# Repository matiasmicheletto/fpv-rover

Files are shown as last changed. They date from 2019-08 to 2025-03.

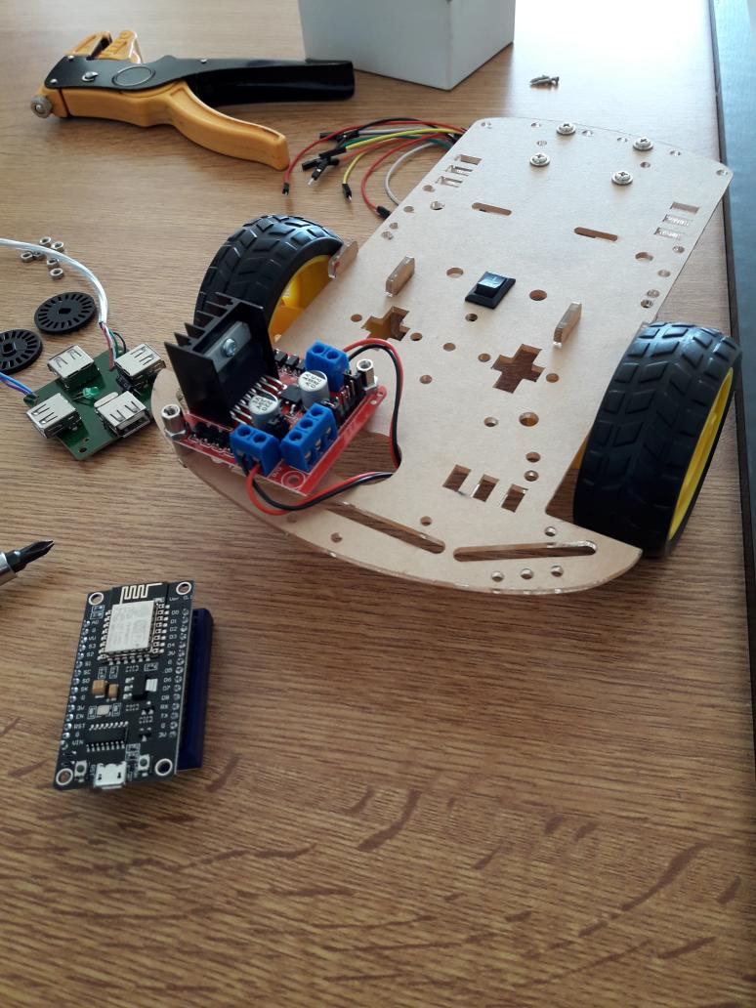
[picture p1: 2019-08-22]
img/v1-assembling/Assembling_2.jpg

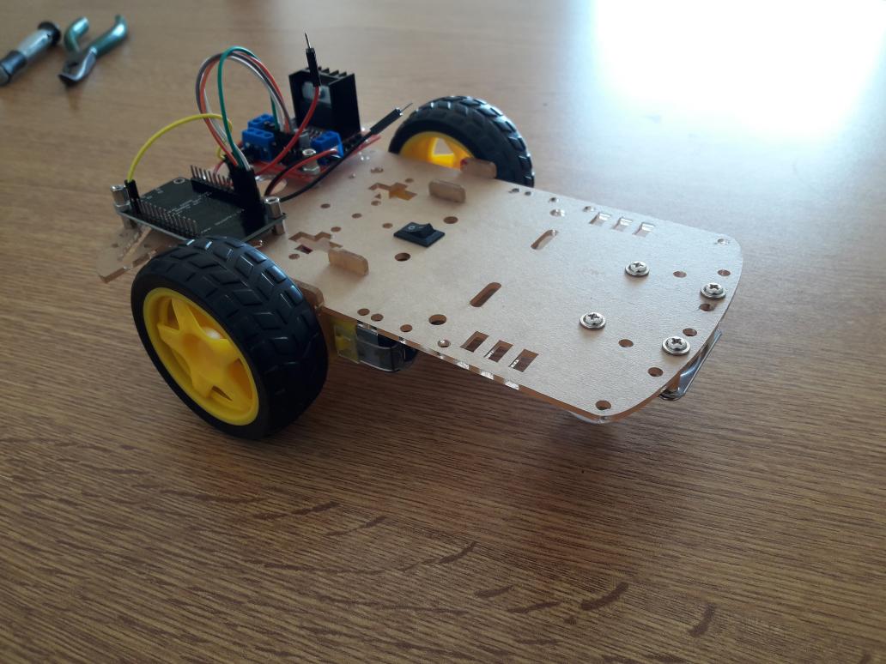
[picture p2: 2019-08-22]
img/v1-assembling/Assembling_3.jpg

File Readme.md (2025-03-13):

# FPV Wi-Fi rover 

A three-wheeled rover built using a prototyping [chassis kit](https://www.amazon.com/perseids-Chassis-Encoder-Wheels-Battery/dp/B07DNYQ3PX) and the [ESP32-CAM](https://www.amazon.com/ESP32-CAM-MB-Aideepen-ESP32-CAM-Bluetooth-Arduino/dp/B0948ZFTQZ/ref=sr_1_2_sspa) board.  

By means of a HUD Display running in your browser, you can see the rover's point of view, and by moving the cursor over the screen, you can control the rover through WebSocket commands.  

## Demo
Demo (https://www.youtube.com/watch?v=7270GWGmxQA)  

## Requirements

  - ESP32-CAM.  
  - L298n Dual Full-Bridge.  
  - Kit 3 wheeled robot: chassis, motors, wheels and battery sockets.  
  - WiFi network (no internet needed).  
  - Web browser with WebSocket API support.  

## Getting started

  1. Build the rover attaching motors to the chasis, L298n bridge, power supply and on-off switch. Use at least 9V as supply, and not higher than 12V. A set of seven 1.5V AA batteries will make the job.     
  2. Create a ``credentials.h`` file in the [firmware/src/](firmware/src/) folder with your local WiFi SSID and password, for example:
  ```cpp
    const char* ssid = "MY_SSID";  
    const char* password = "my_pass";  
  ```
  3. Compile and upload the firmware to the ESP32-CAM board using the corresponding programmer shield. You can use the Arduino IDE or any other platform of your choice.  
  4. Use a serial monitor to see the IP address that your local network provided to the rover's ESP32-CAM board. After that, you can disconnect the board from the programmer shield.  
  5. Connect the microcontroller to the bridge using the pin map configured in [firmware/src/config.h](firmware/src/config.h). Use the 5V output of the bridge as power supply for the microcontroller. Now, the harware configuration is done, and the rover should be ready to use.  
  6. In your computer connected to the same WiFi network of the rover, setup a local server to serve the [client](client/index.html) web application. Open the app with your browser, depending on the server application, usually it is hosted with the URL: http://localhost:8080.   
  7. Set the IP address of the rover in the input and hit the "connect" button. You should see the video captured by the rovers camera as the background of the screen. If that doesn't work, then check the [client/js/index.js](client/js/index.js) script to look for any mismatch between ports or IP configurations.  
  8. That's it, control the rover by moving the cursor over the screen and have fun!  

## License

This project is published under the GPL V3.0 license.

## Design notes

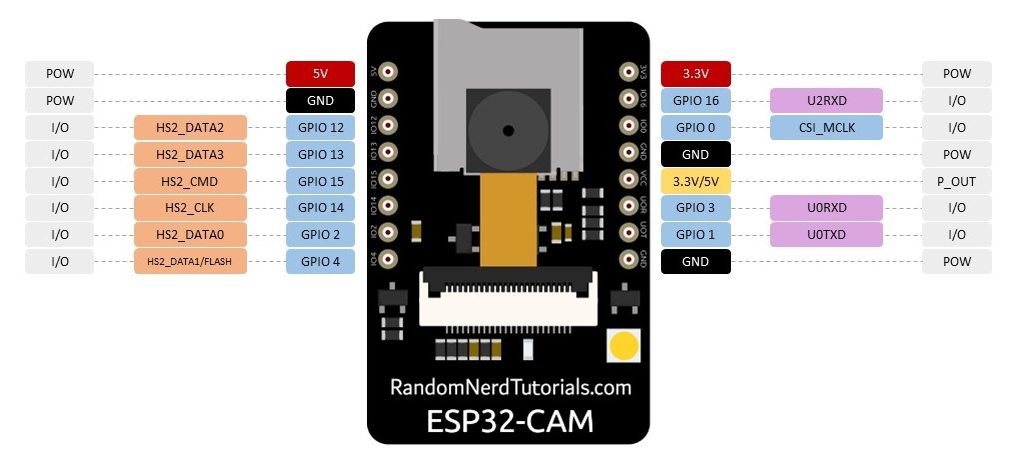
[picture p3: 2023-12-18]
doc/ESP32CAM_pinout.jpg

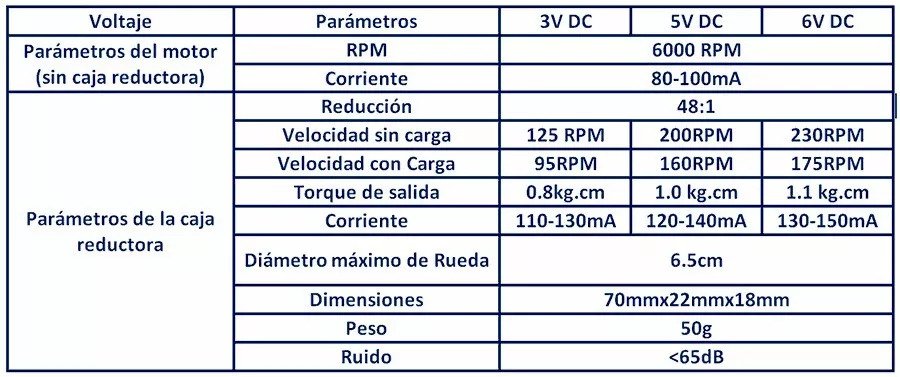
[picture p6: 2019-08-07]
doc/motor.jpg

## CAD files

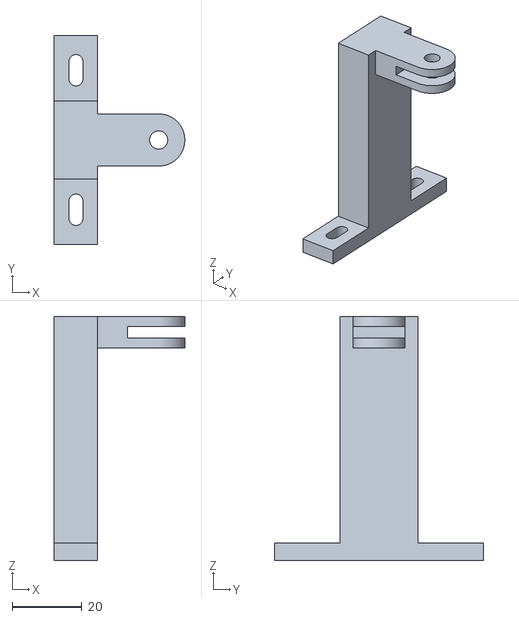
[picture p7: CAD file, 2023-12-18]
3d-models/gopro_mount_chasis.stl
37.5 x 60.0 x 70.0

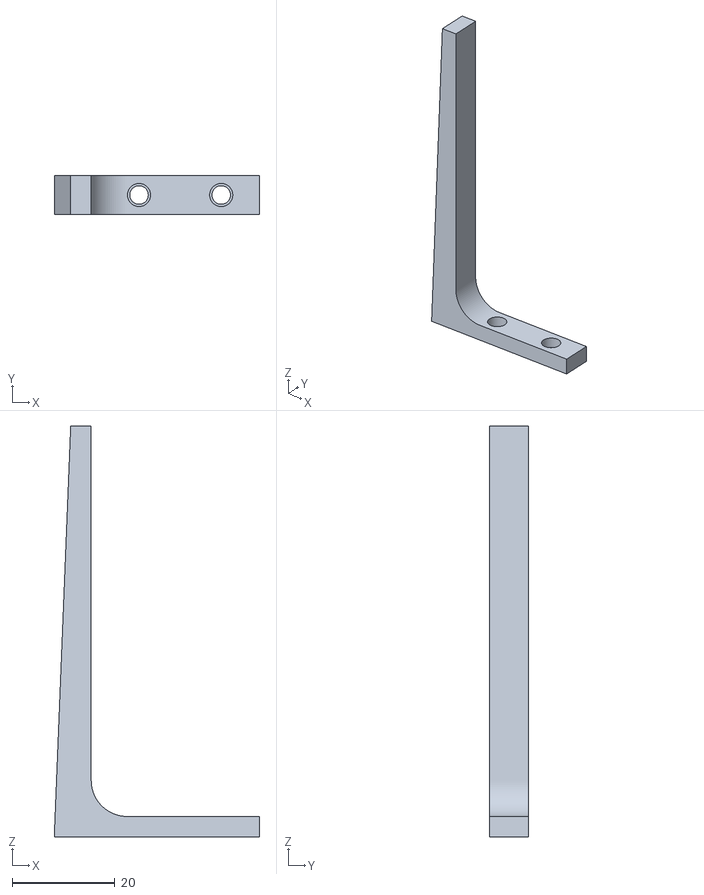
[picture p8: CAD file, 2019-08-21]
3d-models/smartphone_holder.stl
40.0 x 7.50 x 80.0

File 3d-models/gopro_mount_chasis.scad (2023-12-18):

$fn = 100;

// Adapter dimensions
Ro = 7.5;
Ri = 2.6;
L = 35;
Lc = 17;
Hc = 3.2;
Ht = 2.9;

// Holder and base dimensions
Wb = 12.5; // Base width
Lb = 60; // Base length
Hbb = 5; // Base height
Hbt = 65; // Holder height (mounted on base)
rh = 2; // Hole radius
lh = 5; // Hole length (from circles centers)
Sh = 40; // Holes separation



module half(){
    translate([L/2, 0, 0])
        difference(){
            union(){
                cylinder(h = Ht, r = Ro, center = true);
                translate([-L/4, 0, 0])
                    cube([L/2, Ro*2, Ht], center = true);
            }
            cylinder(h = Ht, r = Ri, center = true);
        }
}

module center(){
    translate([Lc/4, 0, Hc/2])
        cube([Lc/2, Ro*2, Hc], center = true);
}


module adapter() {
    translate([0,0,(Hc+Ht)/2]) half();
    translate([0,0,-(Hc+Ht)/2]) half();
    translate([0,0,-Hc/2]) center();
}

module screw_hole() {
    linear_extrude(height = Hbb, center = true, convexity = 10, twist = 0)
    hull() {
        translate([0,lh/2,0]) circle(rh);
        translate([0,-lh/2,0]) circle(rh);
    }
}
    

module base() {
    union() { // Base and holder
        difference() { // Base with holes
            cube([Wb, Lb, Hbb], center = true);
            translate([0, Sh/2, 0]) screw_hole();
            translate([0, -Sh/2, 0]) screw_hole();
        }
        translate([0, 0, (Hbb+Hbt)/2])
            cube([Wb, 3*Ro, Hbt], center = true);
    }
}

module holder() {
    base();
    translate([Wb/2,0,Hbb/2+Hbt-Ht-Hc/2]) adapter();
}

holder();

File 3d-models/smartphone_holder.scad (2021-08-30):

$fn=50;

// Dimensiones
L = 40; // Largo del pie
H = 80; // Altura
W = 7.5; // Ancho
R = 7; // Radio curvatura angulo
// Orificios para tornillos
sep = 16; // Separacion
db = 7.5; // Distancia al borde del pie
// Largo y alto a quitar para el ahuecamiento central
L2 = L*0.82; 
H2 = H-4; 
// Dimensiones rectangulo diagonal
w = L-L2-H+H2; 
s = sqrt(H*H+w*w); 

module rem(){
    union(){ // Recorte interior
        translate([(L-L2+R)/2,0,(H-H2)/2])
            cube([(L2-R),W,H2], center = true);
        
        translate([(L-L2)/2,0,(H-H2+R)/2])
            cube([L2,W,H2-R], center = true);
        
        translate([L/2-L2+R,0,H/2-H2+R])
        rotate([0,90,90])
            cylinder(r = R, h = W+1, center = true);
    }
    
    // Recorte diagonal
    translate([-L/2,-W/2,-H/2])
    rotate([0,-asin(H/s),0])
        cube([s,W,w*H/s]);
}

module holes(){
        
    Rh1 = 2.25; // Radio para cabeza del tornillo
    Rh2 = 1.8; // Radio para rosca del tornillo
    ph = 1.5; // Espesor de la zona de ajuste

    translate([L/2-db,0,-H2/2+ph/2])
        cylinder(r = Rh1, h = H-H2-ph, center = true);
    translate([L/2-db,0,-H2/2])
        cylinder(r = Rh2, h = H-H2, center = true);
    
    translate([L/2-db-sep,0,-H2/2+ph/2])
        cylinder(r = Rh1, h = H-H2-ph, center = true);
    translate([L/2-db-sep,0,-H2/2])
        cylinder(r = Rh2, h = H-H2, center = true);
}


difference(){
    cube([L,W,H], center = true);
    rem();
    holes();
}

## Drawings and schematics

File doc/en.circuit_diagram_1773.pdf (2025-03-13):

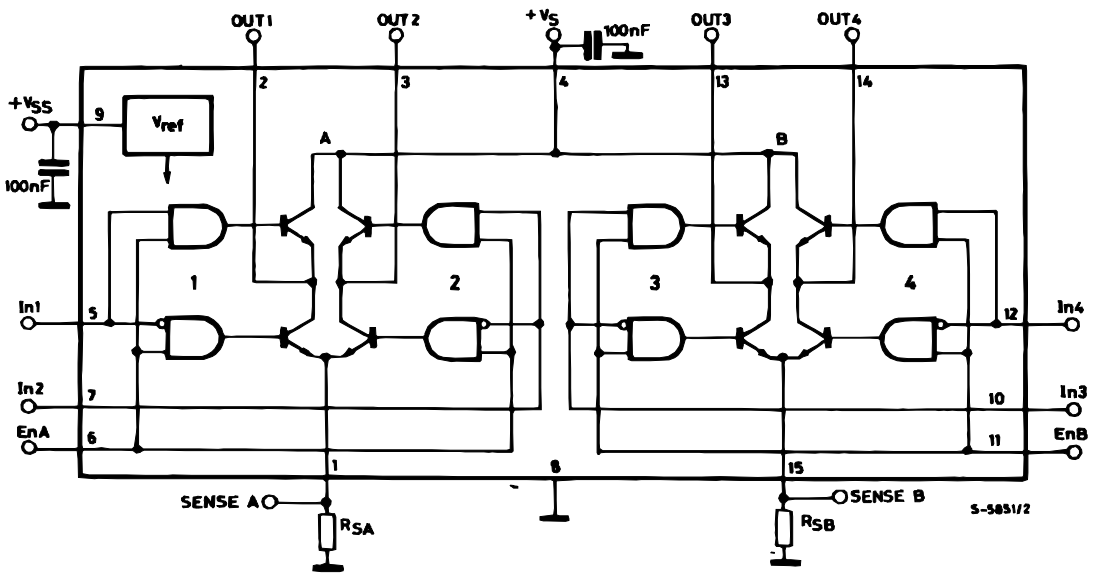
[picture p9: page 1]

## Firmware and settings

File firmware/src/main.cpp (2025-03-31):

#include <WiFi.h>
#include "WebSocketsServer.h"
#include "esp_camera.h"
//#include "LiquidCrystal_I2C.h"
#include "credentials.h" // WiFi credentials
#include "config.h"
#include "esp_timer.h"

#ifdef RS232_DEBUG
  #define DEBUG_PRINT(x) Serial.print(x)
  #define DEBUG_PRINTLN(x) Serial.println(x)
  #define DEBUG_PRINTF(...) Serial.printf(__VA_ARGS__)
#else
  #define DEBUG_PRINT(x)
  #define DEBUG_PRINTLN(x)
  #define DEBUG_PRINTF(...)
#endif

void startCameraServer(int& port); // Prototype

WebSocketsServer web_socker_server(WSS_PORT);  
uint8_t client_num; // Number of clients 
bool wss_connected = false;
void web_socket_event(uint8_t client, WStype_t type, uint8_t * payload, size_t length);

// LiquidCrystal_I2C lcd(LCD_ADDR, LCD_COLS, LCD_ROWS); 

// Ouput pwm values goes from 0 to PWM_MAX (255 for 8-bit PWM)
// Setpoints and speed values go from -PWM_MAX to PWM_MAX (negative values for backward)
// Client setpoints and feedback values are in the range 0 to 2*PWM_MAX
int left_setpoint = 0; // Left setpoint and rotation direction <- left motor speed sent by client. Values between -PWM_MAX and PWM_MAX
int right_setpoint = 0; // Right setpoint and rotation direction <- right motor speed sent by client. Values between -PWM_MAX and PWM_MAX
int left_speed = 0; // Left motor speed and rotation direction. Values between -PWM_MAX and PWM_MAX
int right_speed = 0; // Right motor speed and rotation direction. Values between -PWM_MAX and PWM_MAX

 // Output updating counter. Resets outputs if no input, so client must keep controlling rover
int watchdog = 0;

// Flash control
bool flash_blinking = false;
bool flash_on = false;
int flash_counter = 0;
int max_flash_count = 3; // Number of times to blink (negative values for infinite)
volatile uint32_t flash_blink_period = 25; // default period is 250ms

/* Timer interrupt variables
 * The real-time operating system consists on 4 tasks: 
    - 0: Web socket server loop: 10ms (1 slot), 
    - 1: Motor control outputs update: 20ms (2 slots)
    - 2: Feedback update: 100ms (10 slots)
    - 3: Flash led blinking period: 250ms (25 slots) by default, but configurable
*/
volatile uint32_t timerticks[4] = {0, 0, 0, 0}; 
hw_timer_t * timer = NULL;


int parse_value(char * ptr, int size) { // Convert char array to integer
  int value = 0;
  for (int i = 0; i < size; i++) {
    if (ptr[i] < '0' || ptr[i] > '9') // Error handling
      return 0; 
    value = value * 10 + (ptr[i] - '0'); 
  }
  return value;
}


int clamp_motor_speed(int speed) { // Clamp low speeds to prevent motor stalling
  return speed < CLAMP_THRES ? 0 : speed;
}


int get_speed(int setpoint, int speed) { // Exponential smoothing acceleration
  return (int) (INERT * (float) setpoint + (1-INERT) * (float) speed);
}


void IRAM_ATTR on_timer_tick() {
  timerticks[0]++; // Web socket server loop
  timerticks[1]++; // Motor control outputs update
  timerticks[2]++; // Feedback update
  timerticks[3]++; // Flash led blinking period  
}


// Websocket server events callback
void web_socket_event(uint8_t client, WStype_t type, uint8_t * payload, size_t length) {
  switch(type) {
    case WStype_CONNECTED: { // Client connected -> get IP and print it on serial port
      IPAddress ip = web_socker_server.remoteIP(client);
      DEBUG_PRINTF("[%u] WSS connection from IP: %d.%d.%d.%d\n", client, ip[0], ip[1], ip[2], ip[3]);
      wss_connected = true;
      break;
    }
    case WStype_DISCONNECTED:{ // Client disconnected, closed browser, not WiFi, etc.
      DEBUG_PRINTF("[%u] WSS disconected!\n", client);
      wss_connected = false;
      break;
    }
    case WStype_TEXT:{ // Client sent a message
      client_num = client;
      // Payload must have 6 digit from 000 to 2*PWM_MAX (510 for 8-bit PWM)
      if(length != 6){
        DEBUG_PRINTF("Invalid payload length: %d\n", length);
        break;
      }
      // Convert both values to integer and update setpoints
      const int pd = 3; // Number of digits in payload for each value
      left_setpoint = parse_value((char*) payload, pd) - PWM_MAX;
      right_setpoint = parse_value((char*) payload + pd, pd) - PWM_MAX;
      DEBUG_PRINTF("New setpoints: (%d,%d) \n", left_setpoint, right_setpoint);
      watchdog = 0; // Reset watchdog when updating setpoints
      break;
    }
  }
}


void send_feedback() { // Send current motor speeds to client
  if(wss_connected){
    const int left_feedback = left_speed + PWM_MAX;
    const int right_feedback = right_speed + PWM_MAX;
    char payload[7];
    sprintf(payload, "%03d%03d", left_feedback, right_feedback); // Format payload as 6 digits
    web_socker_server.sendTXT(client_num, payload); // Send values to client
    DEBUG_PRINTF("Sent values: (%d,%d) \n", left_feedback, right_feedback);
  }
}


void flash_blink(){ // Start blinking flash LED
  flash_blinking = true;
}


void update_flash() { // Update flash LED state
  if(flash_blinking){
    if(max_flash_count > 0 && flash_counter >= max_flash_count){ // Stop blinking condition
      flash_blinking = false;
      flash_counter = 0;
      analogWrite(FLASH_LED_NUM, 0);
    }else{ // Alternate between on and off
      analogWrite(FLASH_LED_NUM, flash_on ? PWM_MAX : 0);
      flash_on = !flash_on;
      flash_counter++;
    }
  }
}


void critical_error() { // Idle mode
  left_setpoint = 0;
  right_setpoint = 0;
  max_flash_count = -1; // Infinite blinking
  flash_blink_period = 10; // Blink every 100ms
  flash_blink(); // Blink flash LED to indicate motor stopping
  DEBUG_PRINTF("Critical error, waiting for reset\n");
  //while(true){};
}


void update_motors_speed() {

  watchdog++;

  // If no input after a set of loops, stop motors
  // Watchdog is reset when new setpoints are received
  if(watchdog >= MAX_WATCHDOG){ 
    left_setpoint = 0;
    right_setpoint = 0;
    if(left_speed != 0 || right_speed != 0){ // While halting, blink flash LED
      DEBUG_PRINTF("Watchdog timeout, halting rover\n. Current speed: (%d,%d)\n", left_speed, right_speed);
      flash_blink();
    }
    watchdog = MAX_WATCHDOG; // Prevents watchdog overflow
  }

  // Compute motor speeds (PWM value)
  left_speed = get_speed(left_setpoint, left_speed);
  right_speed = get_speed(right_setpoint, right_speed);

  // Update outputs
  if(left_speed >= 0){ // Left motor forward
    analogWrite(FL_PIN, clamp_motor_speed(left_speed));
    analogWrite(BL_PIN, 0);
  }else{ // Left motor backward
    analogWrite(FL_PIN, 0);
    analogWrite(BL_PIN, clamp_motor_speed(PWM_MAX + left_speed));
  }

  if(right_speed >= 0){ // Right motor forward
    analogWrite(FR_PIN, clamp_motor_speed(right_speed));
    analogWrite(BR_PIN, 0);
  }else{ // Right motor backward
    analogWrite(FR_PIN, 0);
    analogWrite(BR_PIN, clamp_motor_speed(PWM_MAX + right_speed));
  }
}


void setup() {
  #ifdef RS232_DEBUG
    Serial.begin(BAUDRATE);
    DEBUG_PRINTF("Setting up system...\n");
  #endif

  pinMode(LED_GPIO_NUM, OUTPUT);
  pinMode(FLASH_LED_NUM, OUTPUT);
  
  // Set ouput modes
  pinMode(FL_PIN, OUTPUT);
  pinMode(FR_PIN, OUTPUT);
  pinMode(BL_PIN, OUTPUT);
  pinMode(BR_PIN, OUTPUT);
  // Disable outputs (set motors off)
  analogWrite(FL_PIN, 0);
  analogWrite(FR_PIN, 0);
  analogWrite(BL_PIN, 0);
  analogWrite(BR_PIN, 0);

  /*
  lcd.init();
  lcd.backlight(); 
  */

  // OV260 config
  camera_config_t config;
  config.ledc_channel = LEDC_CHANNEL_0;
  config.ledc_timer = LEDC_TIMER_0;
  config.pin_d0 = Y2_GPIO_NUM;
  config.pin_d1 = Y3_GPIO_NUM;
  config.pin_d2 = Y4_GPIO_NUM;
  config.pin_d3 = Y5_GPIO_NUM;
  config.pin_d4 = Y6_GPIO_NUM;
  config.pin_d5 = Y7_GPIO_NUM;
  config.pin_d6 = Y8_GPIO_NUM;
  config.pin_d7 = Y9_GPIO_NUM;
  config.pin_xclk = XCLK_GPIO_NUM;
  config.pin_pclk = PCLK_GPIO_NUM;
  config.pin_vsync = VSYNC_GPIO_NUM;
  config.pin_href = HREF_GPIO_NUM;
  config.pin_sccb_sda = SIOD_GPIO_NUM;
  config.pin_sccb_scl = SIOC_GPIO_NUM;
  config.pin_pwdn = PWDN_GPIO_NUM;
  config.pin_reset = RESET_GPIO_NUM;
  //config.xclk_freq_hz = 10000000;
  config.xclk_freq_hz = 20000000;
  //config.frame_size = FRAMESIZE_QVGA;
  config.frame_size = FRAMESIZE_VGA;
  config.pixel_format = PIXFORMAT_JPEG;
  config.grab_mode = CAMERA_GRAB_WHEN_EMPTY;
  config.fb_location = CAMERA_FB_IN_PSRAM;
  //config.jpeg_quality = 12;
  config.jpeg_quality = 8;
  config.fb_count = 1;
  config.grab_mode = CAMERA_GRAB_LATEST;
  if(psramFound()){
    DEBUG_PRINTF("PSRAM found\n");
    config.jpeg_quality = 10;
    config.fb_count = 2;
    config.grab_mode = CAMERA_GRAB_LATEST;
  } else { // Limit the frame size when PSRAM is not available
    DEBUG_PRINTF("PSRAM not found\n");
    config.frame_size = FRAMESIZE_SVGA;
    config.fb_location = CAMERA_FB_IN_DRAM;
  }

  esp_err_t err = esp_camera_init(&config);
  if (err != ESP_OK) {
    DEBUG_PRINTF("Camera init failed with error 0x%x", err);
    critical_error();
    return;
  }else{
    DEBUG_PRINTF("Camera initialized\n");
  }

  sensor_t *s = esp_camera_sensor_get();
  s->set_quality(s, 63);
  s->set_agc_gain(s, 16);
  s->set_whitebal(s, 1);
  s->set_gain_ctrl(s, 0);
  s->set_aec_value(s, 6);

  DEBUG_PRINTF("Initializing WiFi connection");
  bool connected = false;
  IPAddress ip;
  int tries = 0;
  while(!connected){
    WiFi.begin(ssid, password);
    WiFi.setSleep(false);
    while (WiFi.status() != WL_CONNECTED) {
      digitalWrite(LED_GPIO_NUM, LOW);
      delay(250);
      DEBUG_PRINTF(".");
      digitalWrite(LED_GPIO_NUM, HIGH);
      delay(250);
      tries++;
    }
    ip = WiFi.localIP();
    if(ip[0] != 0){
      connected = true;
    }else{
      tries++;
      DEBUG_PRINTF("\nIP Error, retrying...");
      if(tries > WIFI_CONNECT_ATTEMPTS){
        DEBUG_PRINTF("Failed to connect to WiFi after %d attempts\n", tries);
        critical_error();
        return;
      }
    }
  }
  DEBUG_PRINTF("Done\n");

  web_socker_server.begin();
  web_socker_server.onEvent(web_socket_event);
  DEBUG_PRINTF("Web Socket Server listening on http://%d.%d.%d.%d:%d\n", ip[0], ip[1], ip[2], ip[3], WSS_PORT);

  int port = CAM_PORT;
  startCameraServer(port); // Get streaming port
  s->set_xclk(s, LEDC_TIMER_0, 40); // After boot, set 40MHz for clock freq
  DEBUG_PRINTF("Camera stream URL: http://");
  DEBUG_PRINTF("%d.%d.%d.%d:%d/stream \n", ip[0], ip[1], ip[2], ip[3], port); 

  // Configure Timer 2 (Timer Group 1, Timer 2)
  timer = timerBegin(2, 80, true);  // Timer 2, prescaler 80 -> 1 tick = 1μs
  timerAttachInterrupt(timer, &on_timer_tick, true);
  timerAlarmWrite(timer, 10000, true); // Interrupt every 10ms (10000µs)
  timerAlarmEnable(timer); // Enable timer

  flash_blink();
}

void loop() {

  // Time slot is 10ms

  if(timerticks[0] >= 1){ // 10ms
    web_socker_server.loop();
    timerticks[0] = 0;
  }

  if(timerticks[1] >= 2){ // 20ms
    update_motors_speed();  
    timerticks[1] = 0;
  }

  if(timerticks[2] >= 10){ // 100ms
    send_feedback();
    timerticks[2] = 0;
  }

  if(timerticks[3] >= flash_blink_period){
    update_flash();
    timerticks[3] = 0;
  }
}

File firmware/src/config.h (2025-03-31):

// Misc
#define BAUDRATE 115200 // Serial communication speed
#define RS232_DEBUG 1 // Print debug messages
#define INERT 0.3 // Acceleration inertia factor
#define MAX_WATCHDOG 10 // Max. number of loops before all stop
#define INT_EPS 1 // Epsilon for integer comparison
#define PWM_MAX 255 // Max. PWM value (8 bits)
#define CLAMP_THRES 100 // Clamp threshold for motor pwm outputs

#define WIFI_CONNECT_ATTEMPTS 50 // Max number of attempts to connect to WiFi

// Server ports
// Make sure to change the ports in the client's code
#define CAM_PORT 80 
#define WSS_PORT 82

// OV260 pinout
#define CAMERA_MODEL_AI_THINKER
#define PWDN_GPIO_NUM     32
#define RESET_GPIO_NUM    -1
#define XCLK_GPIO_NUM      0
#define SIOD_GPIO_NUM     26
#define SIOC_GPIO_NUM     27
#define Y9_GPIO_NUM       35
#define Y8_GPIO_NUM       34
#define Y7_GPIO_NUM       39
#define Y6_GPIO_NUM       36
#define Y5_GPIO_NUM       21
#define Y4_GPIO_NUM       19
#define Y3_GPIO_NUM       18
#define Y2_GPIO_NUM        5
#define VSYNC_GPIO_NUM    25
#define HREF_GPIO_NUM     23
#define PCLK_GPIO_NUM     22
#define LED_GPIO_NUM      33
#define FLASH_LED_NUM     4

// GPIO
#define FL_PIN 13 // Left forward --> In_3
#define BL_PIN 14 // Left backward --> In_4
#define FR_PIN 15 // Right forward --> In_1
#define BR_PIN 2 // Right backward --> In_2


/* Not using LCD for now
#define LCD_ADDR 0x27 // Or 0x3F if not working
#define LCD_COLS 20
#define LCD_ROWS 4
*/

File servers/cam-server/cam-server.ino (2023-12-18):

#include "esp_camera.h"
#include <WiFi.h>

#define CAMERA_MODEL_AI_THINKER
#include "camera_pins.h"

const char* ssid = "Pauwifi-Radanet";
const char* password = "r4s6e57q";

void startCameraServer();
void setupLedFlash(int pin);

void setup() {
  Serial.begin(115200);
  Serial.setDebugOutput(true);
  Serial.println();

  camera_config_t config;
  config.ledc_channel = LEDC_CHANNEL_0;
  config.ledc_timer = LEDC_TIMER_0;
  config.pin_d0 = Y2_GPIO_NUM;
  config.pin_d1 = Y3_GPIO_NUM;
  config.pin_d2 = Y4_GPIO_NUM;
  config.pin_d3 = Y5_GPIO_NUM;
  config.pin_d4 = Y6_GPIO_NUM;
  config.pin_d5 = Y7_GPIO_NUM;
  config.pin_d6 = Y8_GPIO_NUM;
  config.pin_d7 = Y9_GPIO_NUM;
  config.pin_xclk = XCLK_GPIO_NUM;
  config.pin_pclk = PCLK_GPIO_NUM;
  config.pin_vsync = VSYNC_GPIO_NUM;
  config.pin_href = HREF_GPIO_NUM;
  config.pin_sccb_sda = SIOD_GPIO_NUM;
  config.pin_sccb_scl = SIOC_GPIO_NUM;
  config.pin_pwdn = PWDN_GPIO_NUM;
  config.pin_reset = RESET_GPIO_NUM;
  config.xclk_freq_hz = 20000000;
  config.frame_size = FRAMESIZE_UXGA;
  config.pixel_format = PIXFORMAT_JPEG; // for streaming
  //config.pixel_format = PIXFORMAT_RGB565; // for face detection/recognition
  config.grab_mode = CAMERA_GRAB_WHEN_EMPTY;
  config.fb_location = CAMERA_FB_IN_PSRAM;
  config.jpeg_quality = 12;
  config.fb_count = 1;
  
  // if PSRAM IC present, init with UXGA resolution and higher JPEG quality
  //                      for larger pre-allocated frame buffer.
  if(config.pixel_format == PIXFORMAT_JPEG){
    if(psramFound()){
      config.jpeg_quality = 10;
      config.fb_count = 2;
      config.grab_mode = CAMERA_GRAB_LATEST;
    } else {
      // Limit the frame size when PSRAM is not available
      config.frame_size = FRAMESIZE_SVGA;
      config.fb_location = CAMERA_FB_IN_DRAM;
    }
  } else {
    // Best option for face detection/recognition
    config.frame_size = FRAMESIZE_240X240;
#if CONFIG_IDF_TARGET_ESP32S3
    config.fb_count = 2;
#endif
  }

#if defined(CAMERA_MODEL_ESP_EYE)
  pinMode(13, INPUT_PULLUP);
  pinMode(14, INPUT_PULLUP);
#endif

  // camera init
  esp_err_t err = esp_camera_init(&config);
  if (err != ESP_OK) {
    Serial.printf("Camera init failed with error 0x%x", err);
    return;
  }

  sensor_t * s = esp_camera_sensor_get();
  // initial sensors are flipped vertically and colors are a bit saturated
  if (s->id.PID == OV3660_PID) {
    s->set_vflip(s, 1); // flip it back
    s->set_brightness(s, 1); // up the brightness just a bit
    s->set_saturation(s, -2); // lower the saturation
  }
  // drop down frame size for higher initial frame rate
  if(config.pixel_format == PIXFORMAT_JPEG){
    s->set_framesize(s, FRAMESIZE_QVGA);
  }

#if defined(CAMERA_MODEL_M5STACK_WIDE) || defined(CAMERA_MODEL_M5STACK_ESP32CAM)
  s->set_vflip(s, 1);
  s->set_hmirror(s, 1);
#endif

#if defined(CAMERA_MODEL_ESP32S3_EYE)
  s->set_vflip(s, 1);
#endif

// Setup LED FLash if LED pin is defined in camera_pins.h
#if defined(LED_GPIO_NUM)
  setupLedFlash(LED_GPIO_NUM);
#endif

  WiFi.begin(ssid, password);
  WiFi.setSleep(false);

  while (WiFi.status() != WL_CONNECTED) {
    delay(500);
    Serial.print(".");
  }
  Serial.println("");
  Serial.println("WiFi connected");

  startCameraServer();

  Serial.print("Camera Ready! Use 'http://");
  Serial.print(WiFi.localIP());
  Serial.println("' to connect");
}

void loop() {
  // Do nothing. Everything is done in another task by the web server
  delay(10000);
}

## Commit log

2019-07-31 Lista de materiales
2019-07-31 Configuracion setpoint y salidas pwm
2019-08-01 Script y hoja de estilos separados.
2019-08-01 Emulacion eyetracker con mouse. Feedback de salidas del esp.
2019-08-13 Organizacion directorio. Libreria, driver y server para control por eyetracker
2019-08-14 Ecuaciones de mapeo de coordenadas para control de motores
2019-08-21 Pieza soporte smartphone
    [smartphone_holder.scad, smartphone_holder.stl]
2019-08-21 Control visible. Ajustes pieza soporte smartphone
    [smartphone_holder.scad, smartphone_holder.stl]
2019-08-22 Fix load de video. Parametros knob
2019-08-24 Sliders verticales para mostrar aceleracion y respuesta
2021-08-30 Readme update
    [smartphone_holder.scad]
2023-12-18 Repo refactor
    [gopro_mount_chasis.scad, gopro_mount_chasis.stl, smartphone_holder.scad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]
2024-01-08 ESP32-CAM minimal code for video streaming
2024-01-10 Fix GPIO 16 rebooting board
    [main.cpp]
2025-02-05 Code refactor. Use 8 bit instead of 10 for PWM
2025-03-13 Updated readme. Changed low pass filter to exponential smoothing function
2025-03-14 Fixed setpoint formulae and conversion between client and server
    [config.h, main.cpp]
2025-03-14 Fixed sliders values. Added socket connection status
2025-03-30 Switched camelcase to snake case. Added feedback update as task. Switched VGA to QVGA. Flash blink when halt.
2025-03-31 Set inertia factor to 0.3. Clamp motor speed. Reduced tasks periods.
